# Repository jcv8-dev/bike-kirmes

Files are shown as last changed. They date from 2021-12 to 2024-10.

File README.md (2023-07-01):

# bike-kirmes
Beleuchtung fürs Fahrrad mit verschiedenen bunten Modi
grafik

## Verfügbare Modi
- Einhornkotze/Regenbogen-Welle
- Color fade
- einzelne Farbe
- Stroboskop
- Blaulicht
- Blinker (links/rechts/warnblinker)

### Schalter 1 
- Wechselt zwischen den von dir festgelegten Modi durch
### Schalter 2 (Überschreibt Schalter 1)
- Blinker eine Seite
### Schalter 3 (Überschreibt Schalter 1)
- Blinker andere Seite
### Schalter 4 (Überschreibt Schalter 1-3)
- Ein/Aus

(Der Code für ein animierten Blinker ist vorhanden, aber nicht für 2 aneinanderhängende Segmente optimiert)

# Partslist
|Bauteil|z.B. von |~Preis|
|--|--|-|
|1m WS2812b 144led/m | AliExpress | 10€ |
|Alu U-Profil 2x 50cm x 17,5mm | AliExpress | 5€ |
|Arduino Pro Micro | Ebay | 5€ |
|Motorad Lenker Blinker Schalter | Ebay | 5€ |
|Platine, JST-Stecker und Kabel|AliExpress|5€|
|Halterung für Alu-Profile|3D-Drucker (stl & 3mf hängt an)|30ct|
|Lenkererweiterung als befestigung für den Schalter|AliExpress|4€|

# Was kommt wo dran?
|Bauteil|Pin|
|-|-|
|LEDs|5|
|Schalter 1 (Modus Auswählen)|7|
|Schalter 2 (Blinker 1)|0|
|Schalter 3 (Blinker 2)|3|
|Schalter 4 (An/Aus)|1|

hookup

# LEDs anschließen
Der Code sieht es vor, dass beide LED-Streifen hintereinander hängen.
Bedeutet: Der DatenAusgang der letzten LED des ersten Streifens muss an den Dateneingang der ersten LED des zweiten Streifens angeschlossen werden.

# Code
## Was muss im Code angepasst werden?
- Gesamtanzahl der LEDs (#define NUM xxx)
- Aufteilung der LEDs auf die beiden Segmente (int segment_[1/2] = xx)
- Welche Modi es mit welchen Einstellungen in welcher Reihenfolge gibt
  - Geschwindigkeit der Effekte (int x_delay ist die Pause zwischen Aktualisierungen der LEDs im Effekt x. Je kürzer, desto schneller.)
  - Farben (int x_color[3] {r,g,b,} ist die Farbe des Effekts x mit den Werten r,g,b von je 0-255)
  - Helligkeit (0-255)

# Sonstiges
## Montierung
### LEDs
Ich habe eine einfache 3D-Druckbare Halterung entworfen, in die die U-Profile mit einer Breite von 17,5mm einfach eingeklebt werden können. Diese können dann am Fahrrad an den Montagepunkten für Gepäckträger festgeschraubt werden. Ggf muss die Halterung mit einem Feuerzeug o.ä. leicht angewärmt werden, damit sich die Halterung an krumme Winkel anpassen kann.

### Controller & Powerbank
Ich nutze eine Powerbank mit ~20.000mAh. Diese habe ich in einem 3D-Gedruckten Gehäuse zusammen mit dem Arduino und Fahrradflicken (Man weiß ja nie :) untergebracht. Dieses Gehäuse lebt jetzt in einem meiner Getränkehalter.

## Stromverbrauch
Auf größter Helligkeit löst meine Powerbank teilweise OverCurrent aus. Passe am besten deine Helligkeit an deine Powerbank an. Mit den 20.000mAh komme ich bei einer Helligkeit von ca. 150 bei ±7h raus.

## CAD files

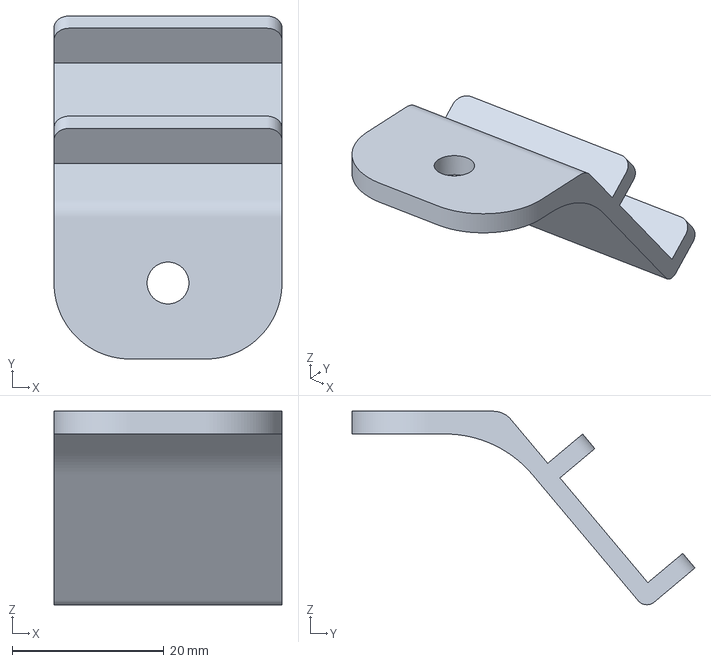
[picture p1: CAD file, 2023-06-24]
led-gepaecktraeger-adapter.3mf
30.0 x 45.1 x 25.5 mm

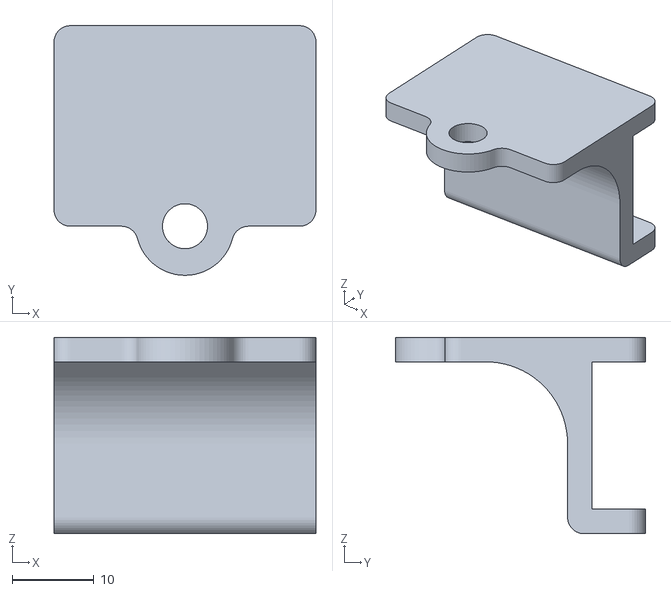
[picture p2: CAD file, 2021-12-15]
ledbarholder.stl
32.0 x 30.5 x 24.0

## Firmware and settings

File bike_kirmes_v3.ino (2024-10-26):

#include <Adafruit_NeoPixel.h>

#define NUM_SEGMENTS 2
#define SEGMENT_NUM_LEDS 70

// LED Definition
#define LED_LEFT_PIN 1
Adafruit_NeoPixel led_left = Adafruit_NeoPixel(SEGMENT_NUM_LEDS, LED_LEFT_PIN, NEO_GRB + NEO_KHZ800);

#define LED_RIGHT_PIN 12
Adafruit_NeoPixel led_right = Adafruit_NeoPixel(SEGMENT_NUM_LEDS, LED_RIGHT_PIN, NEO_GRB + NEO_KHZ800);


// Input Definitions
#define BUTTON 14
#define INDICATOR_LEFT 4
#define INDICATOR_RIGHT 5
#define SWITCH 13

#define SOFTWARE_DEBOUNCE_MS 50
#define BUTTON_LONG_PRESS_THRESHHOLD 400

// Effect Definitions
#define FRAMETIME_MS 10
#define LOOP_LENGTH 100




volatile bool buttonPressed = false;
volatile bool switchActive = false;
volatile bool indicatorLeftActive = false;
volatile bool indicatorRightActive = false;
unsigned long lastDebounceTime = 0;
unsigned long buttonPressTime = 0;
volatile bool longPressActive = false;


Adafruit_NeoPixel segments[] = {led_left, led_right};

int red[] = {255,10,0};
int white[] = {150,150,150};
int amber[] = {255,60,0};
int blue[] = {20,40,200};


#define NUM_MODES 5 //Anzahl Effekte, entsprechend anpassen
typedef void (*FunctionPtr)(int);
FunctionPtr modes[NUM_MODES];

uint mode = 0;

#define NUM_EFFECTS 2
FunctionPtr effects[NUM_EFFECTS];

uint global_frame_counter = 0;

void loadFunctionMap(){
  modes[0] = [](int frame) { rainbow_wave(frame, 45); };
  modes[1] = [](int frame) { rainbow_wave(frame, 200); };
  modes[2] = [](int frame) { single_color(red); };
  modes[3] = [](int frame) { color_fade(frame, 100); };
  modes[4] = [](int frame) { police(frame); };

  effects[0] = [](int frame) { strobe(frame); };
  effects[1] = [](int frame) { brake_light(frame); };

}

void initialize_inputs(){
  pinMode(BUTTON, INPUT_PULLUP);
  pinMode(INDICATOR_LEFT, INPUT_PULLUP);
  pinMode(INDICATOR_RIGHT, INPUT_PULLUP);
  pinMode(SWITCH, INPUT_PULLUP);
}

void initialize_outputs(){
  led_left.begin();
  led_right.begin();
}

void setup() {
  initialize_outputs();
  initialize_inputs();
  loadFunctionMap();
}

void input_polling() {
  button_handler();
  indicator_left_handler();
  indicator_right_handler();
  switch_handler();
}

void loop(){
  for(int frame = 0; frame < LOOP_LENGTH; frame++){
    global_frame_counter++;
    input_polling();
    if(longPressActive && buttonPressed){
      if(switchActive){
        effects[0](frame);
        Serial.println("switchActive");
      } else {
        effects[1](frame);
        Serial.println("!switchActive");
      }
    } else if( indicatorLeftActive){
      indicatorLeft(frame);
      Serial.println("indicatorLeftActive");
    } else if( indicatorRightActive) {
      indicatorRight(frame);
      Serial.println("indicatorRightActive");
    } else {
      Serial.println("else");

      modes[mode](frame);
    }
    Serial.println("delay");

    delay(FRAMETIME_MS);
  }
  Serial.println("loop");

}

int single_color(int color[]){
  for (int i = 0; i < NUM_SEGMENTS; i++){
    for (int j = 0; j < SEGMENT_NUM_LEDS; j++){
      segments[i].setPixelColor(j, segments[i].Color(color[0],color[1],color[2]));
    }
    segments[i].show();
  }
  return 0;
}

int rainbow_wave(int frame, int brightness){
  int hueOffset = (frame * 65535) / LOOP_LENGTH;  // Maps frame number to hue 0-65535
  int spread = 2000; // the higher the number, the fewer leds are between repeating colors
  for (int segment = 0; segment < NUM_SEGMENTS; segment++) {
    for (int i = 0; i < SEGMENT_NUM_LEDS; i++) {
      int hue = (i * spread) - hueOffset;  // Adjust hue based on position and frame
      segments[segment].setPixelColor(i, segments[segment].ColorHSV(hue, 255, brightness));
    }
    segments[segment].show();
  }
  return 0;
}

void color_fade(int frame, int brightness){
  float speed_modifier = 0.5;
  int hueStep = 65535 / LOOP_LENGTH * speed_modifier;
    for (int segment = 0; segment < NUM_SEGMENTS; segment++) {
      for (int i = 0; i < SEGMENT_NUM_LEDS; i++) {
        int hue = global_frame_counter * hueStep;
        segments[segment].setPixelColor(i, segments[segment].ColorHSV(hue, 255, brightness));
      }
    segments[segment].show();
  }
}

void police(int frame) {
  int PATTERN_FLASHES = 3;
  int SHORT_PAUSE = 6;
  int LONG_PAUSE = 12;
  int FLASH_DURATION = 2; // Number of frames LEDs stay on for each flash

  int patternLength = (PATTERN_FLASHES * (FLASH_DURATION + SHORT_PAUSE)) + LONG_PAUSE; // Total pattern cycle length

  // Determine if the current frame is within a flash or pause interval
  int cycleFrame = frame % patternLength; // Frame within the current cycle

  // Calculate if LEDs should be on (flash) or off based on the cycle frame
  bool isFlashOn = false;
  for (int flashIndex = 0; flashIndex < PATTERN_FLASHES; flashIndex++) {
    int flashStart = flashIndex * (FLASH_DURATION + SHORT_PAUSE);
    if (cycleFrame >= flashStart && cycleFrame < flashStart + FLASH_DURATION) {
      isFlashOn = true; // Turn on LEDs during the flash duration
      break;
    }
  }

  // Set LED colors based on whether the current frame is in an "on" or "off" state
  for (int segment = 0; segment < NUM_SEGMENTS; segment++) {
    for (int i = 0; i < SEGMENT_NUM_LEDS; i++) {
      if (isFlashOn) {
        segments[segment].setPixelColor(i, segments[segment].Color(0, 30, 255)); // Set LED to blue
      } else {
        segments[segment].setPixelColor(i, segments[segment].Color(0, 0, 0)); // Turn off LED
      }
    }
    segments[segment].show();
  }
}
void brake_light(int frame){
  int cycleLength = 18;                
  int cycleFrame = frame % cycleLength; 

  bool isOn = (cycleFrame < cycleLength/3); 

  for (int segment = 0; segment < NUM_SEGMENTS; segment++) {
      for (int i = 0; i < SEGMENT_NUM_LEDS; i++) {
        if(isOn){
          segments[segment].setPixelColor(i, segments[segment].Color(255,10,00));
        } else {
          segments[segment].setPixelColor(i, segments[segment].Color(0,0,0));
        }
      }
      segments[segment].show();
  }
}

void strobe(int frame){
  int cycleLength = 6;                
  int cycleFrame = frame % cycleLength; 

  bool isOn = (cycleFrame < cycleLength/2); 

  for (int segment = 0; segment < NUM_SEGMENTS; segment++) {
      for (int i = 0; i < SEGMENT_NUM_LEDS; i++) {
        if(isOn){
          segments[segment].setPixelColor(i, segments[segment].Color(255,255,255));
        } else {
          segments[segment].setPixelColor(i, segments[segment].Color(0,0,0));
        }
      }
      segments[segment].show();
  }
}

void blank(){
  for (int segment = 0; segment < NUM_SEGMENTS; segment++) {
      for (int i = 0; i < SEGMENT_NUM_LEDS; i++) {
        segments[segment].setPixelColor(i, segments[segment].Color(0,0,0));
      }
      segments[segment].show();
  }
}

void button_handler() {
  unsigned long currentTime = millis(); // Get the current time in milliseconds

  // Check the current state of the button
  bool currentButtonState = digitalRead(BUTTON) == LOW;

  // Debounce logic: ignore changes that happen too quickly
  if (currentButtonState != buttonPressed && (currentTime - lastDebounceTime) > SOFTWARE_DEBOUNCE_MS) {
    lastDebounceTime = currentTime;

    if (currentButtonState) {
      // Button is pressed
      buttonPressed = true;
      buttonPressTime = currentTime; // Record the time when the button was pressed
      longPressActive = false;       // Reset long press active state
    } else {
      // Button is released
      buttonPressed = false;
      longPressActive = false;       // Reset long press active state when released
      unsigned long pressDuration = currentTime - buttonPressTime;

      if (pressDuration < BUTTON_LONG_PRESS_THRESHHOLD) {
        button_handle_short_press(); // Handle short press
      } 
    }
  }

   // Handle continuous long-press while held
  if (buttonPressed && !longPressActive && (currentTime - buttonPressTime >= BUTTON_LONG_PRESS_THRESHHOLD)) {
    longPressActive = true;          // Set long press active
  }


}

void indicatorLeft(int frame){
  int cycleLength = 20;                
  int cycleFrame = frame % cycleLength; 

  bool isOn = (cycleFrame < cycleLength/2); 

  for (int i = 0; i < SEGMENT_NUM_LEDS; i++) {
    if(isOn){
      segments[0].setPixelColor(i, segments[0].Color(255,50,00));
      segments[1].setPixelColor(i, segments[1].Color(0,0,0));
    } else {
      segments[0].setPixelColor(i, segments[0].Color(0,0,0));
    }
  }
  segments[0].show();
  segments[1].show();
}

void indicatorRight(int frame){
 int cycleLength = 20;                
  int cycleFrame = frame % cycleLength; 

  bool isOn = (cycleFrame < cycleLength/2); 

  for (int i = 0; i < SEGMENT_NUM_LEDS; i++) {
    if(isOn){
      segments[1].setPixelColor(i, segments[0].Color(255,50,00));
      segments[0].setPixelColor(i, segments[1].Color(0,0,0));
    } else {
      segments[1].setPixelColor(i, segments[0].Color(0,0,0));
    }
  }
  segments[0].show();
  segments[1].show();
}

void button_handle_short_press() {
  mode++;
  mode %= NUM_MODES;
} 

void indicator_left_handler(){
  indicatorLeftActive = digitalRead(INDICATOR_LEFT) == LOW;
}
void indicator_right_handler(){
  indicatorRightActive = digitalRead(INDICATOR_RIGHT) == LOW;
}
void switch_handler(){
  switchActive = digitalRead(SWITCH) == LOW;
}

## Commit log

2023-06-24 Neue Version der Alu-Profil-Halterung
    [led-gepaecktraeger-adapter.3mf]
2023-06-24 Funktionsaufrufe Modulare und parametrisiert
2023-06-25 Cleanup und Kommentare
2024-10-26 Create bike_kirmes_v3.ino
    Needs rework from loop to global frame counter
    [bike_kirmes_v3.ino]
